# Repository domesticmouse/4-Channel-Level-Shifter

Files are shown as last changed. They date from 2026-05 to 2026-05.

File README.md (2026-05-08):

# 4-Channel Bidirectional Level Shifter

## Overview

This board is a 4-channel bidirectional logic level converter designed to safely
interface between different voltage domains (typically 3.3V and 5V). It is based
on the [Adafruit 4-channel I2C-safe Bi-directional Logic Level Converter][]. See
the [Adafruit learn documentation][] on converting
[I2C data lines between 3.3V and 5V][] for context on this circuit.

[Adafruit 4-channel I2C-safe Bi-directional Logic Level Converter]: https://www.adafruit.com/product/757
[Adafruit learn documentation]: https://learn.adafruit.com/
[I2C data lines between 3.3V and 5V]: https://learn.adafruit.com/introducing-adafruit-stemma-qt/technical-specs#data-lines-3035228

## Technical Specifications

- **Core Logic:** 4x [BSS138 N-channel MOSFETs][].
- **Pull-up Resistors:** 10kΩ on all input/output signal lines.
- **Voltage Range:**
  - **LV (Low Voltage):** Typically 1.8V to 3.3V.
  - **HV (High Voltage):** Typically up to 5V (limited by MOSFET Vgs/Vds).
- **Decoupling:** 100nF ceramic capacitors on both power rails for noise suppression.

[BSS138 N-channel MOSFETs]: https://www.lcsc.com/product-detail/C5224260.html

## Pinout

### J1 (High Voltage Side)

| Pin | Label | Description |
| --- | --- | --- |
| 1 | **5V** | High Voltage Power Rail (e.g., 5V) |
| 2 | **HV1** | Channel 1 High Side |
| 3 | **HV2** | Channel 2 High Side |
| 4 | **HV3** | Channel 3 High Side |
| 5 | **HV4** | Channel 4 High Side |
| 6 | **GND** | Ground |

### J2 (Low Voltage Side)

| Pin | Label | Description |
| --- | --- | --- |
| 1 | **3.3V** | Low Voltage Power Rail (e.g., 3.3V) |
| 2 | **LV1** | Channel 1 Low Side |
| 3 | **LV2** | Channel 2 Low Side |
| 4 | **LV3** | Channel 3 Low Side |
| 5 | **LV4** | Channel 4 Low Side |
| 6 | **GND** | Ground |

## PCB Features

- **Form Factor:** Approximately 18.8mm x 18.4mm.
- **Signal Integrity:** Solid ground planes on both layers with stitching vias.
- **Usability:** Silkscreen labeling for all channels and power pins.

## Usage Guide

1. **Power:** Connect your low-voltage supply to **3.3V** and your high-voltage supply to **5V**.
2. **Ground:** Connect **GND** to your common system ground.
3. **Logic:** Connect your 3.3V logic signals to the **LVn** pins; the corresponding **HVn** pins will provide the 5V shifted output (and vice-versa for bidirectional signals).

## Board render

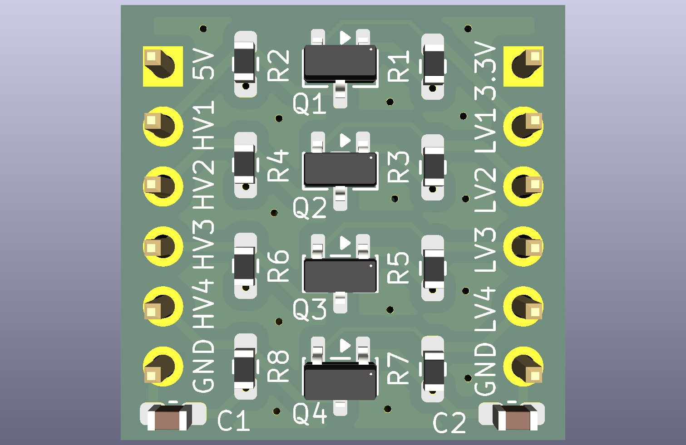
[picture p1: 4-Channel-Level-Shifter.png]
Board render


---
*Developed as a KiCad 10 project.*

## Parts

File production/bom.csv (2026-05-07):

Designator | Footprint | Quantity | Value | LCSC Part #
C1, C2 | 0603 | 2 | 100nF | C14663
J1 | PinHeader_1x06_P2.54mm_Vertical | 1 | 5V side | C37208
J2 | PinHeader_1x06_P2.54mm_Vertical | 1 | 3.3V side | C37208
Q1, Q2, Q3, Q4 | SOT-23 | 4 | BSS138 | C5224260
R1, R2, R3, R4, R5, R6, R7, R8 | 0603 | 8 | 10kΩ | C2906982

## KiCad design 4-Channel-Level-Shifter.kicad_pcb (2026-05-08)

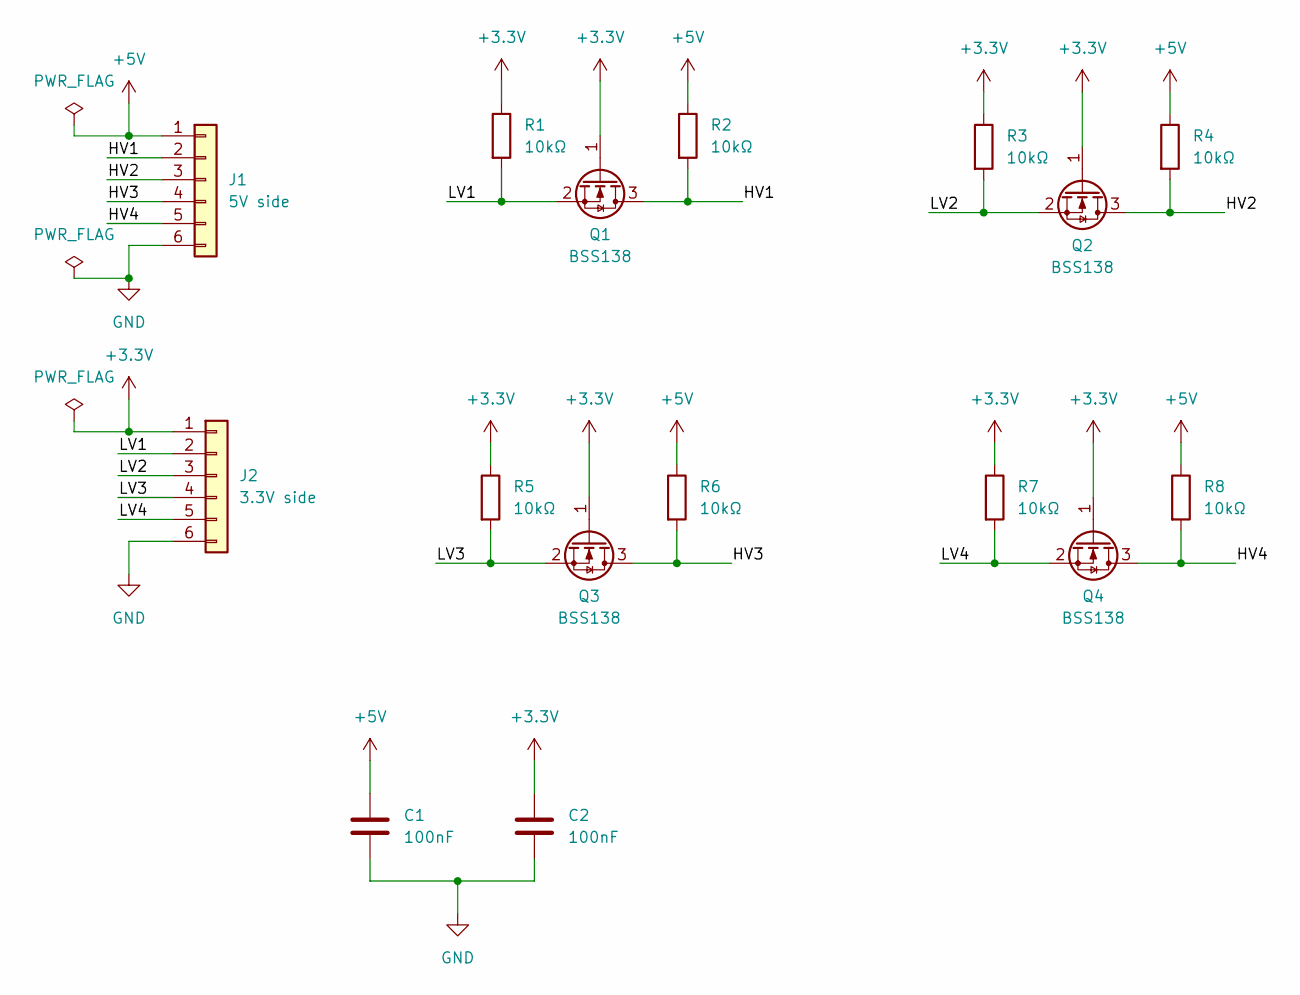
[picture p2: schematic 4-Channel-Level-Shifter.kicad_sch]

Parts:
C1, C2: 100nF; C_0603_1608Metric_Pad1.08x0.95mm_HandSolder; LCSC C14663
J1: 5V side; PinHeader_1x06_P2.54mm_Vertical; LCSC C37208
J2: 3.3V side; PinHeader_1x06_P2.54mm_Vertical; LCSC C37208
Q1, Q2, Q3, Q4: BSS138; SOT-23; LCSC C5224260
R1, R2, R3, R4, R5, R6, R7, R8: 10kΩ; R_0603_1608Metric_Pad0.98x0.95mm_HandSolder; LCSC C2906982

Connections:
+3.3V: C2.1, J2.1, Q1.1 (G), Q2.1 (G), Q3.1 (G), Q4.1 (G), R1.1, R3.1, R5.1, R7.1
+5V: C1.1, J1.1, R2.1, R4.1, R6.1, R8.1
/HV1: J1.2, Q1.3 (D), R2.2
/HV2: J1.3, Q2.3 (D), R4.2
/HV3: J1.4, Q3.3 (D), R6.2
/HV4: J1.5, Q4.3 (D), R8.2
/LV1: J2.2, Q1.2 (S), R1.2
/LV2: J2.3, Q2.2 (S), R3.2
/LV3: J2.4, Q3.2 (S), R5.2
/LV4: J2.5, Q4.2 (S), R7.2
GND: C1.2, C2.2, J1.6, J2.6

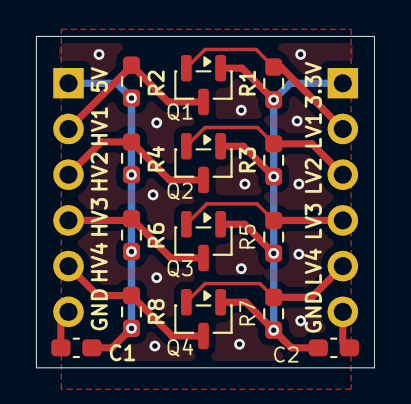
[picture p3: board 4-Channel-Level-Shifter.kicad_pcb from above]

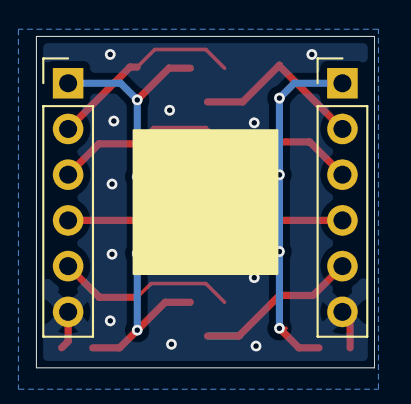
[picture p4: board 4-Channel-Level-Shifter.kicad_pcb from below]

Board: 2 copper layers, 18.8 x 18.4 mm, 16 parts (2 on the bottom side), 11 nets.

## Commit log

2026-05-07 Update schematic
    [4-Channel-Level-Shifter.kicad_pcb, 4-Channel-Level-Shifter.kicad_sch]
2026-05-07 Add production files
    [bom.csv, designators.csv, positions.csv]
2026-05-08 Add dimension between connectors
    [4-Channel-Level-Shifter.kicad_pcb]
